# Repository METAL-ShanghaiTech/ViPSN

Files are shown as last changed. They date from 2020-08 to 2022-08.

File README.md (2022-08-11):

# ViPSN 2.0 (debug version)

English | [简体中文](./README.zh-CN.md)

**ViPSN** (acronym of vibration-powered sensing node) is a programmable Internet of Things (IoT) platform for the development of vibration- or motion-powered sensing and transmitting systems. It serves as a reconfigurable developing platform for vibration-powered IoT applications.

<!-- ## System overview -->

<!-- ## Project structure -->

## Setup and usage

Coming soon! This is debug version (2021-03-05) of ViPSN. 
Right now we are working on a way to get hardware to users, please contact the authors for more information (email: lixin1@shanghaitech.edu.cn or liangjr@shanghaitech.edu.cn). 
For now, feel **free** to explore the hardware and software designs, but be sure to **cite** our work.
```
@ARTICLE{9169698,
  author={X. {Li} and L. {Teng} and H. {Tang} and J. {Chen} and H. {Wang} and Y. {Liu} and M. {Fu} and J. {Liang}},
  journal={IEEE Internet of Things Journal}, 
  title={ViPSN: A Vibration-Powered IoT Platform}, 
  year={2021},
  volume={8},
  number={3},
  pages={1728-1739},
  doi={10.1109/JIOT.2020.3016993}}
```
## Prerequisites
### Hardware design
- Altium Designer (version 9.4 or above) is used for the PCB design.
### Software design
- Keil5 is required to compile the software. 

<!-- ### Software Provided 

In **EGU** and **ETU** folders, this project provides the [Audio](./VSU/Audio/Example) file, which is played by resonant speaker. [AudioGenerator](./VSU/Audio/AudioGenerator.m) can be edited to generate a stable audio wave and . Also, the 3D model file is provided. More details are shown in [VSU README.md](./VSU/README.md).

In **EEU** folder, here are four types circuit model, SEH, self-power P-SSHI, self-power SECE, self-power S-SSHI.

In **EMU** folder, here is a PCB file.

In **EUU** folder, this project provides the [Transmitter Part](.\EUU\software\EUU_trans\examples) and [Receive Part](.\EUU\software\Receiver). And [PCB file](.\EUU\pcb) is also included.  -->

## Related publications
- Qiang Liu, Xin Li, Hao Zhang, Jing Ren*, Shuo Yang, Leitao Cao, Junrui Liang*, Shengjie Ling*, "IntelliSense silk fibroin ionotronic batteries for wildfire detection and alarm," Nano Energy, vol. 101, art. no. 107630, Oct. 2022.
- Jianjun Wang*, Yalei Cao, Hongjun Xiang, Zhiwei Zhang, Junrui Liang, Xin Li, Deyun Ding, Teng Li, and Lihua Tang, "A piezoelectric smart backing ring for high-performance power generation subject to train induced steel-spring fulcrum forces," Energy Conversion and Management, vol. 257, art. no. 115442, 2022.
- Jinxi Zhang, Shaobo Gong, Xin Li, Junrui Liang, Zhong Lin Wang*, and Kailiang Ren*, "A wind‐driven poly (tetrafluoroethylene) electret and polylactide polymer‐based hybrid nanogenerator for self‐powered temperature detection system," Advanced Sustainable Systems, art. no. 2000192. 2021.
- Xin Li, Li Teng, Hong Tang, Haoyu Wang, Yu Liu, Minfan Fu, and Junrui Liang*, “ViPSN: a vibration-powered IoT platform,” IEEE Internet of Things Journal, vol. 8, no. 3, pp. 1728-1739, 2021. 
- Xin Li, Hong Tang, Yiyao Zhu and Junrui Liang*, “Power solution of a vibration-powered sensing node,” Proceedings of the 9th International Power Electronics and Motion Control Conference, Nanjing, China, May 31-June 3, 2020. (IPEMC - ECCE Asia 2020). 
- Xin Li, Hong Tang, Bao Zhao, and Junrui Liang*, “System design and implementation of a transient-motion-powered IoT sensor node,” Proceedings of the ASME 2020 Conference on Smart Materials, Adaptive Structures and Intelligent Systems, Irvine, CA, USA, September 14–16, 2020. (SMASIS 2020) (Finalist of Best Student Hardware Competision).
- Xin Li, Hong Tang, Junrui Liang*, and Lihua Tang, "Exploring the magnetic plucking motion towards a transient-motion-powered IoT sensor node", Proceedings of SPIE Conference 11376, Active and Passive Smart Structures and Integrated Systems IX, 113761U, 22 April 2020. (SPIE SS/NDE 2020).
- Kang Zhao, Yuheng Zhao, and Junrui Liang*, “Live Demo of A Vibration-Powered Bluetooth Sensor with Running PFC Power Conditioning”, Proceedings of the 2017 IEEE International Symposium on Circuits and Systems, Baltimore, USA, May 2017. (ISCAS 2017).
- Kang Zhao, Yuheng Zhao, and Junrui Liang*, “A vibration-powered Bluetooth wireless sensor node with running PFC power conditioning”, Proceedings of the 2017 IEEE International Symposium on Circuits and Systems, Baltimore, USA, May 2017. (ISCAS 2017).

## Contributors
- Yuheng Zhao and Kang Zhao contributed early on to the hardware designs in 2017.
- Xin Li proposed and designed the system of ViPSN in 2019. 
- Hong Tang implemented the hardwares of system.
- Prof. Junrui Liang oversaw, funded, and originated the project.

## Funding
This research was supported by the grants from the National Natural Science Foundation of China (Project No. 61401277) and ShanghaiTech University (Project No. F-0203-13-003).

## License
```
Apache License
Copyright 2020 Xin Li and Junrui Liang.

Licensed under the Apache License, Version 2.0 (the "License");
you may not use this file except in compliance with the License.
You may obtain a copy of the License at

    http://www.apache.org/licenses/LICENSE-2.0

Unless required by applicable law or agreed to in writing, software
distributed under the License is distributed on an "AS IS" BASIS,
WITHOUT WARRANTIES OR CONDITIONS OF ANY KIND, either express or implied.
See the License for the specific language governing permissions and
limitations under the License.
```
## Contact
If you have technical problems, please contact: lixin1@shanghaitech.edu.cn or china.lixin1@gmail.com.

For business cooperation, please contact: liangjr@shanghaitech.edu.cn.

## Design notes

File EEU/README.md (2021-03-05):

# Energy Enhancement Unit (EEU)

The **EEU** offers the following options:

- standard interface circuit ([SEH]);
- self-power parallel synchronized switch harvesting on inductor  ([SP-P-SSHI]);
- self-power series synchronized switch harvesting on inductor  ([SP-S-SSHI]).

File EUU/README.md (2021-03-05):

# Energy User Unit (EUU)

A programmable BLE SoC (system on chip) nRF52832 by Nordic Inc. serves as the EUU. The EUU has three parts: transceiver, sensor, and CPU. The sensor part uses the on-chip temperature sensor in nRF52832. 
Two remote edge devices are designed for receiving the signals sent out by ViPSN. 
One is a cell phone, which runs a customized mobile app as the EDU module. 
Another is a host PC, which installs a USB BLE receiver module and data processing
program. 
More detailed explanation can be referred to paper ([ViPSN: A Vibration-Powered IoT Platform](../README.md/#divtop)).

## Software

The EUU software includes the two version:

- ESB

    - [Example 1](./software/ESB_version/Transmitter_for_EUU/examples/ESB_template/case_of_intermittent_vibrations/pca10040/blank/arm5_no_packs/)
    - [Example 2](./software/ESB_version/Transmitter_for_EUU/examples/ESB_template/case_of_transient_excitation/pca10040/blank/arm5_no_packs/)
    - [Receiver](./software/ESB_version/Receiver_for_EUU/project/)

    The main differences between above two examples are as follows:

    ```c
    //it has two types of timer, one is being ticked repeating with the interval set before     
    err_code = app_timer_create(&m_led_toggle_timer_id,
                                    APP_TIMER_MODE_REPEATED,
                                    led_toggle_timeout_handler);
    ```

    ```c
    //the other is being ticked singlely	
    err_code = app_timer_create(&m_led_toggle_timer_id,
                                APP_TIMER_MODE_SINGLE_SHOT,
                                led_toggle_timeout_handler);
    ```

- BLE beacon
    - [Example 3](./software/beacon_version/examples/ble_peripheral/ble_app_beacon/pca10040/s132/arm5_no_packs/)

<!-- ## How to install keil5

 Go to [here](http://www2.keil.com/mdk5 ) to download keil5.

It is necessary to activate keil5 before compiling code.

Device is nordic nRF52832-QFAA.

The following pack are required after installing keil5:

1. NordicSemiconductor.nRF_DeviceFamilyPack.8.17.0.pack
2. NordicSemiconductor::Device:Startup:8.9.0
3. ARM.CMSIS.4.5.0

When open [project](.\EUU\software\EUU_trans\examples\case of bridge vibration\pca10040\blank\arm5_no_packs), the dialog box will pop and remind installing above packs. 

After automatically installing, keil5 can complier the project. 

JLINK is recommended to download hex file. If JLINK is not available for developers, STLINK is also available.  -->

<!-- ### Code & Project

In EUU, there are two example projects. 

Developers should build and download it. If something go wrong, please read **Problems may encountered**.

The brief explanation for the project is following:

#### Bridge 

Code can be opened [here](.\EUU\software\EUU_trans\examples\case of bridge vibration\pca10040\blank\arm5_no_packs).

**BUTTON_TOUCH** is the IO port set. 

When **BUTTON_TOUCH** is rising edge, IO interrupt starts. 

When it is falling edge, IO interrupt stops. 

When IO interrupt starts, a timer starts at the same time. 

The timer is set by **LED_TOGGLE_INTERVAL**. 

After timer overflows, **led_toggle_timeout_handler** function is called. 

In this case, it only has a function named **s_tx()**. Developers can change this function to its custom function. 

This function starts high frequency clk at the beginning, then collecting temperature sensor data, sending by ESB, delaying 200ms, and then changing clk from high frequency to low frequency.

In this Bridge case, the timer will repeat according to **LED_TOGGLE_INTERVAL**. And it repeats until IO port is falling edge.

#### Transient 

Code can be opened [here](.\EUU\software\EUU_trans\examples\case of transient excitation\pca10040\blank\arm5_no_packs).

**BUTTON_TOUCH** is the IO port set. 

When **BUTTON_TOUCH** is rising edge, IO interrupt starts. 

When it is falling edge, IO interrupt stops. 

When IO interrupt starts, a timer starts at the same time. 

The timer is set by **LED_TOGGLE_INTERVAL**. 

After timer overflows, **led_toggle_timeout_handler** function is called. Then the timer closes before IO detects it is falling edge. 

In this case, it only has a function named **s_tx()**. Developers can change this function to its custom function. 

This function starts high frequency clk at the beginning, then collecting temperature sensor data, sending by ESB, delaying 200ms, and then changing clk from high frequency to low frequency.

In this Transient case, the timer will only be singly ticked. And it repeats until IO port is falling edge. -->

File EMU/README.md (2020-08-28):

# Energy Management Unit (EMU)

<!-- **EMU** plays an essential role to guarantee the robust and reliable operation under complicated vibration conditions.
It is responsible not only for providing temporary capacitive energy storage for the extra harvested energy from **ETU**, but also for supplying power at a constant voltage to **EUU**.
On the other hand, many vibration sources are intermittent, variable, and unpredictable, so vibration-powered devices should operate in various vibration environments, such as intermittent mode or transient mode.
**EMU** has to maximize the harvested energy income from the supply side, minimize the energy dissipation in energy conversion, and properly deliver power on the user’s demand.
The software program should be carried out with an awareness of the stored energy
level.
However, most off-the-shelf commercial regulators IC only emphasized stable logic voltage output.
Necessary interactions between energy storage and EUU were not sufficiently supported.
For example, LTC3588 (Linear Technology Co.) integrates a low-loss full-wave bridge rectifier and a high-efficiency buck converter for PEH power conditioning.
Its power good output pin (PGOOD) is actually used for indicating the availability of stable output voltage, rather than the stored energy level. -->

In this project, an enhanced EMU is developed by making complementary design to the off-the-shelf commercial regulator. 
It produces necessary energy-level indicating signals to the energy user for better operation under fluctuating or intermittent vibrations.
EMU has three parts: 
1. LTC3588 is used for regulation purpose. Its dc-dc power conversion efficiency is around 80% to 90% under different input voltage, output voltage, and loading current. 
2. MIC841, a micro-power, precision-voltage comparator with adjustable hysteresis is used to provide energy indicating signals.
Via adjusting the resistor network, we can change the threshold of stored energy level so that to carry out different functions.
3. A capacitor is used to store harvested energy.

During the operation, the EMU provides two internal energy-level indicating signals to itself and three external signals to the EUU, such that **ViPSN** can properly handle different tasks. 
P<sub>start</sub> sets when V<sub>store</sub> > 5 V and P<sub>close</sub> sets when V<sub>store</sub> < 3.4 V. 
P<sub>start</sub> starts the dc-dc power conversion of LTC3588. 
P<sub>close</sub> turns off the converter. 
There might be several rounds of lockouts and restarts before the output voltage reaches a stable level, because of the depletion and refill of the storage capacitor. 
Besides the fixed UVLO thresholds, the PGOOD pin of LTC3588 offers further information on the output voltage stability.
The PGOOD pin is logic high when the output voltage of LTC3588 is above 92% of the desired regulation voltage. 
If Vcc falls below this threshold, it turns to logic low. 
It should be noted that PGOOD is not a storage-level indicating signal. 
P<sub>good</sub> added in this study provides a real storage-level indicating signal.
It comes with the rising edge of the comparator’s output. 
It denotes that the storage capacitor of EMU has gained sufficient energy to ensure the execution of the most power-consuming atomic operation. 
P<sub>sleep</sub> comes with the falling edge of the comparator’s output. 
It warns that the energy storage of EMU is in shortage; therefore, the EUU must take an emergent process to save the critical data and then go to the ultralowpower deep-sleep mode. 
In addition, via adjusting the resistor network of the comparator, we can change the voltage thresholds for generating P<sub>good</sub> and P<sub>sleep</sub> so as to ensure proper operations under different excitation conditions.

More information about the working principle of EMU can be referred to paper ([ViPSN: A Vibration-Powered IoT Platform](../README.md/#divtop) and [Power solution of a vibration-powered sensing node](../README.md/#divtop2)).

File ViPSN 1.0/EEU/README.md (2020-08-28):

# Energy Enhancement Unit (EEU)

The **EEU** offers the following options:

- standard interface circuit ([SEH](./circuit/SEH));
- self-power parallel synchronized switch harvesting on inductor  ([SP-P-SSHI](./circuit/SP-P-SSHI));
- self-power series synchronized switch harvesting on inductor  ([SP-S-SSHI](./circuit/SP-S-SSHI)).

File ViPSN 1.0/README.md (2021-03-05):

# ViPSN 1.0
ViPSN

**ViPSN** (acronym of vibration-powered sensing node) is a programmable Internet of Things (IoT) platform for the development of vibration- or motion-powered sensing and transmitting systems. It serves as a reconfigurable developing platform for vibration-powered IoT applications. The whole set of **ViPSN** assembles six basic modules: a vibration emulator as the energy generation unit (**EGU**); a piezoelectric transducer as the energy transduction unit (**ETU**); a power-boosting interface circuit as the energy enhancement unit (**EEU**); a dc-dc regulator with energy-level indicating signals as the energy management unit (**EMU**); a Bluetooth low energy (BLE) module as the energy user unit (**EUU**); and a mobile app as the edge demonstration unit (**EDU**). All units or modules are connected with easy mechanical joggle joints and electrical plunger pin contacts.

## Prerequisites
### Hardware design
- Altium Designer (version 9.4 or above) is used for the PCB design.
- Solidworks (version 2018 or above) is used for 3D-printer case.
### Software design
- Keil5 is required to compile the software. 

### Specification
<table style="border-collapse: collapse; border: none; border-spacing: 0px;">
	<tr>
		<td style="border-width: 1px; border-style: solid; border-color: rgb(0, 0, 0); text-align: center; padding-right: 3pt; padding-left: 3pt;">
			<b>Unit</b>
		</td>
		<td colspan="3" style="border-width: 1px; border-style: solid; border-color: rgb(0, 0, 0); text-align: center; padding-right: 3pt; padding-left: 3pt;">
			<b>Specification</b>
		</td>
	</tr>
	<tr>
		<td style="border-width: 1px; border-style: solid; border-color: rgb(0, 0, 0); text-align: center; padding-right: 3pt; padding-left: 3pt;">
			EGU
		</td>
		<td style="border-width: 1px; border-style: solid; border-color: rgb(0, 0, 0); text-align: center; padding-right: 3pt; padding-left: 3pt;">
			Resonant speaker
		</td>
		<td style="border-width: 1px; border-style: solid; border-color: rgb(0, 0, 0); text-align: center; padding-right: 3pt; padding-left: 3pt;">
			Type
		</td>
		<td style="border-width: 1px; border-style: solid; border-color: rgb(0, 0, 0); text-align: center; padding-right: 3pt; padding-left: 3pt;">
			ADIN-B1BT
		</td>
	</tr>
	<tr>
		<td rowspan="4" style="border-width: 1px; border-style: solid; border-color: rgb(0, 0, 0); text-align: center; padding-right: 3pt; padding-left: 3pt;">
			ETU
		</td>
		<td rowspan="2" style="border-width: 1px; border-style: solid; border-color: rgb(0, 0, 0); text-align: center; padding-right: 3pt; padding-left: 3pt;">
			Piezoelectric
			<br>
			 transducer
		</td>
		<td style="border-width: 1px; border-style: solid; border-color: rgb(0, 0, 0); text-align: center; padding-right: 3pt; padding-left: 3pt;">
			Diameter
		</td>
		<td style="border-width: 1px; border-style: solid; border-color: rgb(0, 0, 0); text-align: center; padding-right: 3pt; padding-left: 3pt;">
			30 mm
		</td>
	</tr>
	<tr>
		<td style="border-width: 1px; border-style: solid; border-color: rgb(0, 0, 0); text-align: center; padding-right: 3pt; padding-left: 3pt;">
			Material
		</td>
		<td style="border-width: 1px; border-style: solid; border-color: rgb(0, 0, 0); text-align: center; padding-right: 3pt; padding-left: 3pt;">
			PZT sheet on steel
		</td>
	</tr>
	<tr>
		<td rowspan="2" style="border-width: 1px; border-style: solid; border-color: rgb(0, 0, 0); text-align: center; padding-right: 3pt; padding-left: 3pt;">
			Mass
		</td>
		<td style="border-width: 1px; border-style: solid; border-color: rgb(0, 0, 0); text-align: center; padding-right: 3pt; padding-left: 3pt;">
			Weight
		</td>
		<td style="border-width: 1px; border-style: solid; border-color: rgb(0, 0, 0); text-align: center; padding-right: 3pt; padding-left: 3pt;">
			13 g
		</td>
	</tr>
	<tr>
		<td style="border-width: 1px; border-style: solid; border-color: rgb(0, 0, 0); text-align: center; padding-right: 3pt; padding-left: 3pt;">
			Material
		</td>
		<td style="border-width: 1px; border-style: solid; border-color: rgb(0, 0, 0); text-align: center; padding-right: 3pt; padding-left: 3pt;">
			Steel
		</td>
	</tr>
	<tr>
		<td rowspan="2" style="border-width: 1px; border-style: solid; border-color: rgb(0, 0, 0); text-align: center; padding-right: 3pt; padding-left: 3pt;">
			EEU
		</td>
		<td style="border-width: 1px; border-style: solid; border-color: rgb(0, 0, 0); text-align: center; padding-right: 3pt; padding-left: 3pt;">
			SEH
		</td>
		<td colspan="2" style="border-width: 1px; border-style: solid; border-color: rgb(0, 0, 0); text-align: center; padding-right: 3pt; padding-left: 3pt;">
			Full-wave bridge rectifier
		</td>
	</tr>
	<tr>
		<td style="border-width: 1px; border-style: solid; border-color: rgb(0, 0, 0); text-align: center; padding-right: 3pt; padding-left: 3pt;">
			SP-SSHI
		</td>
		<td colspan="2" style="border-width: 1px; border-style: solid; border-color: rgb(0, 0, 0); text-align: center; padding-right: 3pt; padding-left: 3pt;">
			Parallel SP-SSHI
		</td>
	</tr>
	<tr>
		<td rowspan="3" style="border-width: 1px; border-style: solid; border-color: rgb(0, 0, 0); text-align: center; padding-right: 3pt; padding-left: 3pt;">
			EMU
		</td>
		<td style="border-width: 1px; border-style: solid; border-color: rgb(0, 0, 0); text-align: center; padding-right: 3pt; padding-left: 3pt;">
			DC-DC Converter
		</td>
		<td colspan="2" style="border-width: 1px; border-style: solid; border-color: rgb(0, 0, 0); text-align: center; padding-right: 3pt; padding-left: 3pt;">
			LTC3588-1
		</td>
	</tr>
	<tr>
		<td style="border-width: 1px; border-style: solid; border-color: rgb(0, 0, 0); text-align: center; padding-right: 3pt; padding-left: 3pt;">
			Comparator
		</td>
		<td colspan="2" style="border-width: 1px; border-style: solid; border-color: rgb(0, 0, 0); text-align: center; padding-right: 3pt; padding-left: 3pt;">
			MIC841
		</td>
	</tr>
	<tr>
		<td style="border-width: 1px; border-style: solid; border-color: rgb(0, 0, 0); text-align: center; padding-right: 3pt; padding-left: 3pt;">
			Storage
		</td>
		<td colspan="2" style="border-width: 1px; border-style: solid; border-color: rgb(0, 0, 0); text-align: center; padding-right: 3pt; padding-left: 3pt;">
			Electrolytic capacitor
		</td>
	</tr>
	<tr>
		<td rowspan="2" style="border-width: 1px; border-style: solid; border-color: rgb(0, 0, 0); text-align: center; padding-right: 3pt; padding-left: 3pt;">
			EUU
		</td>
		<td style="border-width: 1px; border-style: solid; border-color: rgb(0, 0, 0); text-align: center; padding-right: 3pt; padding-left: 3pt;">
			SoC
		</td>
		<td colspan="2" style="border-width: 1px; border-style: solid; border-color: rgb(0, 0, 0); text-align: center; padding-right: 3pt; padding-left: 3pt;">
			nRF52832
		</td>
	</tr>
	<tr>
		<td style="border-width: 1px; border-style: solid; border-color: rgb(0, 0, 0); text-align: center; padding-right: 3pt; padding-left: 3pt;">
			Software
		</td>
		<td colspan="2" style="border-width: 1px; border-style: solid; border-color: rgb(0, 0, 0); text-align: center; padding-right: 3pt; padding-left: 3pt;">
			nRF5 SDK V15.2
		</td>
	</tr>
</table>

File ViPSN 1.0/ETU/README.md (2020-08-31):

## Energy Transduction Unit (ETU)
For ETU, the piezoelectric transducer is made of a circular low-cost piezoelectric buzzer, whose rim is fixed at the moving part of the resonance speaker. 
The low-cost generator is good for popularization. 
If this cheap and under-performing structure works well, there is no doubt for other more sophisticated designs. 
A mass is bonded at the center of the round-shape transducer.
When the base (moving part of the vibrator) undergoes vibration, the piezoelectric structure deflects.

### Specification

<table style="border-collapse: collapse; border: none; border-spacing: 0px;">
	<tr>
		<td style="border-width: 1px; border-style: solid; border-color: rgb(0, 0, 0); text-align: center; padding-right: 3pt; padding-left: 3pt;">
			<b>Unit</b>
		</td>
		<td colspan="3" style="border-width: 1px; border-style: solid; border-color: rgb(0, 0, 0); text-align: center; padding-right: 3pt; padding-left: 3pt;">
			<b>Specification</b>
		</td>
	</tr>
	<tr>
		<td rowspan="4" style="border-width: 1px; border-style: solid; border-color: rgb(0, 0, 0); text-align: center; padding-right: 3pt; padding-left: 3pt;">
			ETU
		</td>
		<td rowspan="2" style="border-width: 1px; border-style: solid; border-color: rgb(0, 0, 0); text-align: center; padding-right: 3pt; padding-left: 3pt;">
			Piezoelectric
			<br>
			 transducer
		</td>
		<td style="border-width: 1px; border-style: solid; border-color: rgb(0, 0, 0); text-align: center; padding-right: 3pt; padding-left: 3pt;">
			Diameter
		</td>
		<td style="border-width: 1px; border-style: solid; border-color: rgb(0, 0, 0); text-align: center; padding-right: 3pt; padding-left: 3pt;">
			30 mm
		</td>
	</tr>
	<tr>
		<td style="border-width: 1px; border-style: solid; border-color: rgb(0, 0, 0); text-align: center; padding-right: 3pt; padding-left: 3pt;">
			Material
		</td>
		<td style="border-width: 1px; border-style: solid; border-color: rgb(0, 0, 0); text-align: center; padding-right: 3pt; padding-left: 3pt;">
			PZT sheet on steel
		</td>
	</tr>
	<tr>
		<td rowspan="2" style="border-width: 1px; border-style: solid; border-color: rgb(0, 0, 0); text-align: center; padding-right: 3pt; padding-left: 3pt;">
			Mass
		</td>
		<td style="border-width: 1px; border-style: solid; border-color: rgb(0, 0, 0); text-align: center; padding-right: 3pt; padding-left: 3pt;">
			Weight
		</td>
		<td style="border-width: 1px; border-style: solid; border-color: rgb(0, 0, 0); text-align: center; padding-right: 3pt; padding-left: 3pt;">
			13 g
		</td>
	</tr>
	<tr>
		<td style="border-width: 1px; border-style: solid; border-color: rgb(0, 0, 0); text-align: center; padding-right: 3pt; padding-left: 3pt;">
			Material
		</td>
		<td style="border-width: 1px; border-style: solid; border-color: rgb(0, 0, 0); text-align: center; padding-right: 3pt; padding-left: 3pt;">
			Steel
		</td>
	</tr>
</table>

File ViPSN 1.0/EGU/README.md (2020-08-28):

## Energy Generation Unit (EGU)
For EGU, a commercial portable resonance speaker serves as the vibrator.
It generates vibrations according to the records from real-world environments. 
It is self-contained with a battery pack inside and standard auxiliary port (AUX) for audio input. 
Different from a normal loudspeaker, it does not have a diaphragm. 
It produces sounds by vibrating the contacting hard medium. 
In other words, a resonance speaker can convert the audio signal into structural vibration.
Compared with the expensive and heavy professional vibrator, this portable solution is a better option for the developer working on vibration-powered IoT applications.

### Specification
In this project, we provided a script (acc2wav.m) to convert vibration acceleration data into audio signals.

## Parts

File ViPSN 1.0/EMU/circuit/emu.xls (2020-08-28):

Comment | Description | Designator | Footprint | LibRef | Quantity
CAP | Capacitor | C3, C4 | 6-0805_N | CAP | 2
6.3V | Polarized Capacitor (Radial) | Cr | 3216[1206] | Cap Pol1 | 1
Cap Pol1 | Polarized Capacitor (Radial) | Cstore | HDR1X2 | Cap Pol1 | 1
Socket | Socket | J1, J2, J3, J4, J7, J11 | PIN1 | Socket | 6
10uH |  | L2 | SMD SS16 | INDUCTOR | 1
Res1 | Resistor | Rc1, Rc2, Rc3 | 6-0805_N | Res1 | 3
LTC3588-1 | Nanopower energy harvesting power supply | U1 | LTC 3588-1 | LTC3588-1 | 1
MIC841 |  | U2 | SOT65P210X90-5L20N | Component_1 | 1

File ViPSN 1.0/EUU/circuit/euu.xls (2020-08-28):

Comment | Description | Designator | Footprint | LibRef | Quantity
4.7uF | Capacitor, NP0, ±2% | C1 | 0603C |  | 1
1uF | Capacitor, NP0, ±2% | C2 | 0603C |  | 1
12pF | Capacitor, NP0, ±2% | C3, C5, C10, C18 | 0603C | C0402-12p | 4
100nF | Capacitor, NP0, ±2% | C4, C6, C14 | 0603C |  | 3
100pF | Capacitor, NP0, ±2% | C8 | 0603C |  | 1
NC | Capacitor, NP0, ±2% | C9 | 0603C |  | 1
0.8pF | Capacitor, NP0, ±2% | C13 | 0603C |  | 1
 |  | DEBUG1 | SIP4 - 2.0 | Header 4 | 1
Socket | Socket | J1, J2, J3, J4, J7, J11 | PIN1 | Socket | 6
10uH | High frequency chip inductor ±5% | L1 | 0603 |  | 1
15nH | High frequency chip inductor ±5% | L2, L3 | 0603 |  | 2
nRF52832-QFAA | Multi-protocol Bluetooth Low Energy and 2.4GHz proprietary system-on-chip | U1 | QFN48 |  | 1
32MHz | XTAL SMD 2016, 32MHz, Cl=8pF, Tol: ±10ppm, Stab: ±10ppm | X1 | BT-XTAL_2016 | XTAL_SMD2016_32MHz_8pF_Epson | 1
32.768kHz | EPSON TOYOCOM - FC-135 32.768KHZ ±20PPM,9.0PF - CRYSTAL, SM, WATCH | X2 | XTAL_3215 | XTAL_FC-135 32.768k | 1

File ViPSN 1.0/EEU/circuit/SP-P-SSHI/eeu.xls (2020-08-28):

Comment | Description | Designator | Footprint | LibRef | Quantity
680pF/50V | 贴片电容 | C11, C12 | 0603C | CAP | 2
SS14 | 1 Amp General Purpose Rectifier | D1, D2, D3, D4, D5 | SOD323 | Diode 1N4004 | 5
SS16 | 1 Amp General Purpose Rectifier | D6 | SOD323 | Diode 1N4004 | 1
Socket | Socket | J1, J2, J3, J4, J7, J11 | PIN1 | Socket | 6
1mH |  | L4 | 1812 | INDUCTOR | 1
510K | 贴片电阻 | R1, R2 | 0603 | Res1 | 2
XN4601 | Composite Transistors, XN4601 | T1, T2 | XN4601 | XN4601 | 2

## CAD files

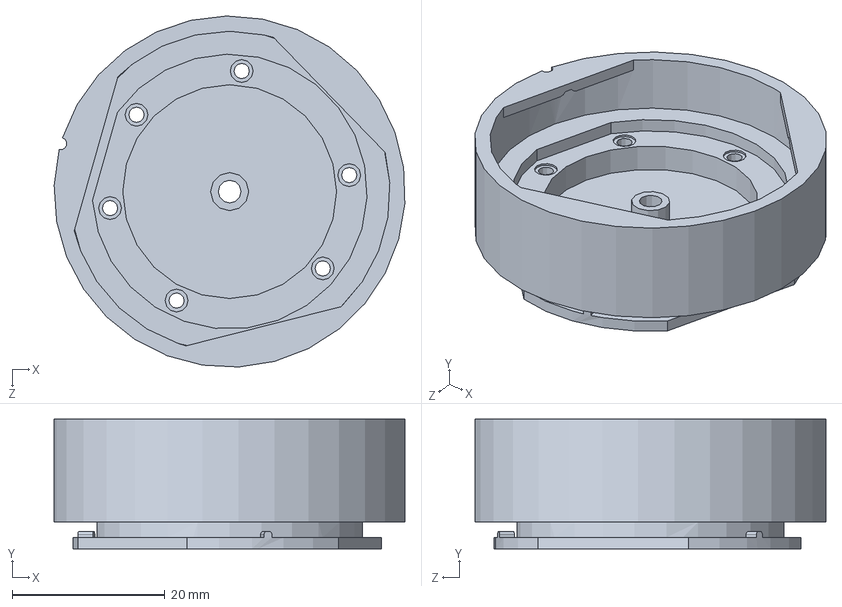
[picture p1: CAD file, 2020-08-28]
ViPSN 1.0/EEU/3d_printer/eeu.SLDPRT
45.9 x 17.0 x 46.0 mm

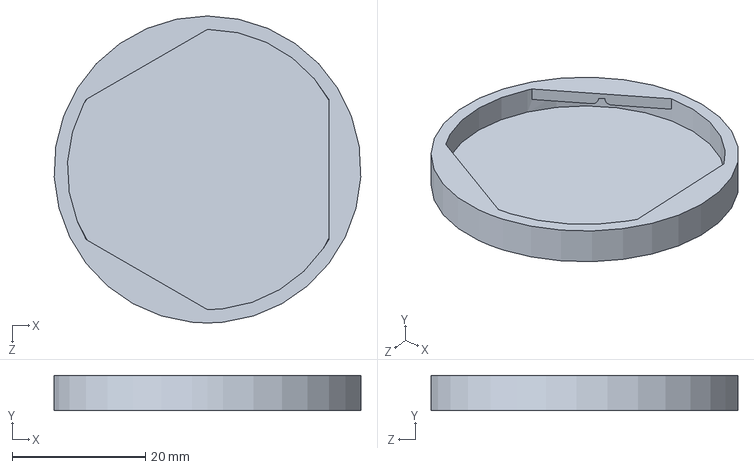
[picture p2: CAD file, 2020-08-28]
ViPSN 1.0/EGU/3d_printer/egu.SLDPRT
45.9 x 5.30 x 46.0 mm

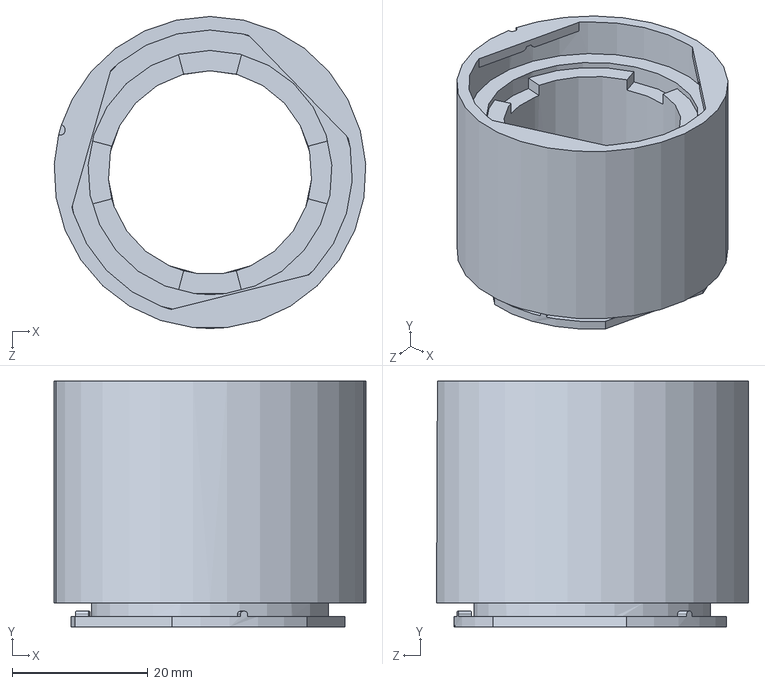
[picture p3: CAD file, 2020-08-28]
ViPSN 1.0/ETU/3d_printer/etu-1.SLDPRT
45.9 x 36.2 x 46.0 mm

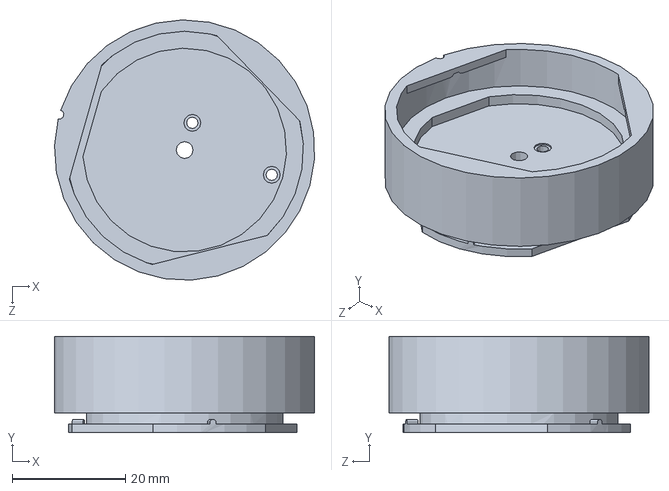
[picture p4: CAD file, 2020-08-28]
ViPSN 1.0/ETU/3d_printer/etu-2.SLDPRT
45.9 x 17.0 x 46.0 mm

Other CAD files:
ViPSN 1.0/EMU/3d_printer/emu.SLDPRT
ViPSN 1.0/EUU/3d_printer/euu.SLDPRT

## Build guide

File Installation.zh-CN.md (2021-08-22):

# EUU环境搭建与测试

## 一、准备工作(以Windows 10平台为例)

* `Keil 5 for Arm`(测试版本MDK527)
* `ARM CMSIS`(测试版本4.5.0)
* `NordicSemiconductor.nRF_DeviceFamilyPack`（测试版本8.17.0）
* `Nordic nRF52832`芯片

### 1、安装并激活Keil

**注意：未激活的Keil有编译代码大小的限制，可能无法完成编译工作。**

### 2、安装`ARM CMSIS`和`NordicSemiconductor.nRF_DeviceFamilyPack`

直接双击安装文件，按照提示即可完成安装。

## 二、EUU结构描述

EUU文件夹下的`software`目录中共有两个版本的工程项目，分别对应`Beacon`协议和Nordic自研的`ESB`通信协议。

以`Beacon`版本为例，在`beacon_version`目录下的文件组织形式与Nordic官方提供的`SDK`例程的组织形式类似。由于本项目使用的芯片是`52832`，所以其对应的`Keil`的启动文件在路径`ViPSN\EUU\software\beacon_version\examples\ble_peripheral\ble_app_beacon\pca10040\s132\arm5_no_packs`下面。

## 三、Keil工程编译

双击打开该`Keil`工程，此时可能会遇到`CMSIS`、`DeviceFamilyPack`缺失的信息，由于前面在安装`Keil`的时候已经安装了相应的文件，所以这里我们选择`否`取消安装。这时，在`Keil`的左侧项目视图中，最下面的`CMSIS`以及`Device`显示是红色，编译工程也会出现错误。

error_1

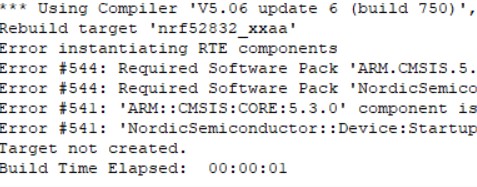
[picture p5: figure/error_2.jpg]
error_2


这时，选择`Keil`上方工具栏中的`Select Software Packs for Target XX`选项卡，在弹出的界面中展开`CMSIS`和`Device Family Pack`选项，取消标红的版本，相应选择刚刚我们自己安装的版本。

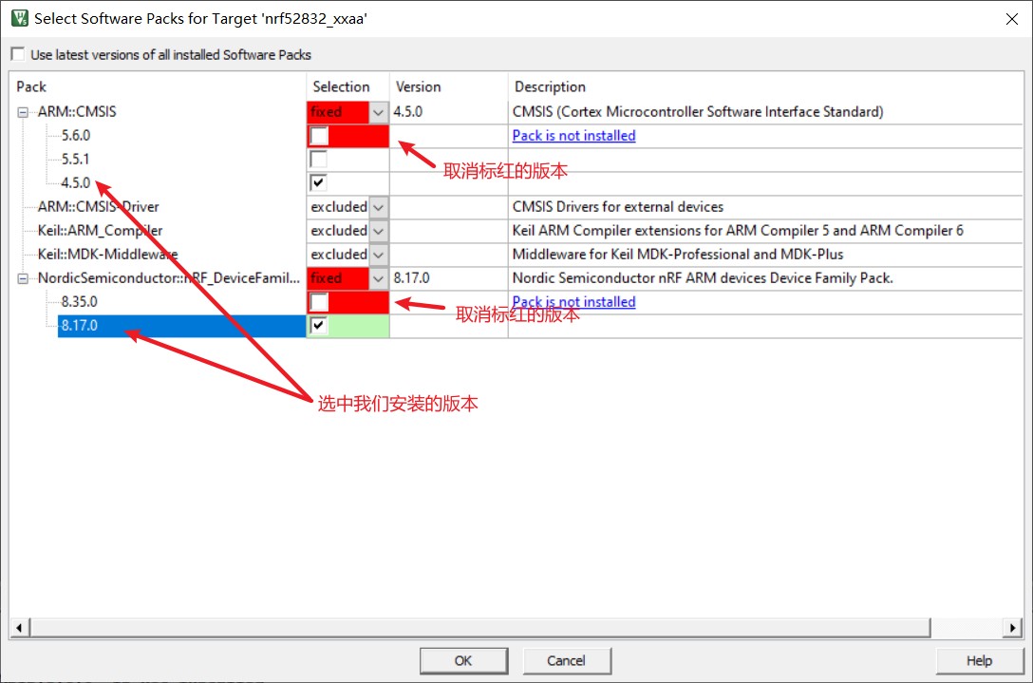
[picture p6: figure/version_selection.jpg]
selection


确定后在弹出的新对话框中，同样展开`CMSIS`以及`Device`选项卡，将标红的版本对应的勾取消。

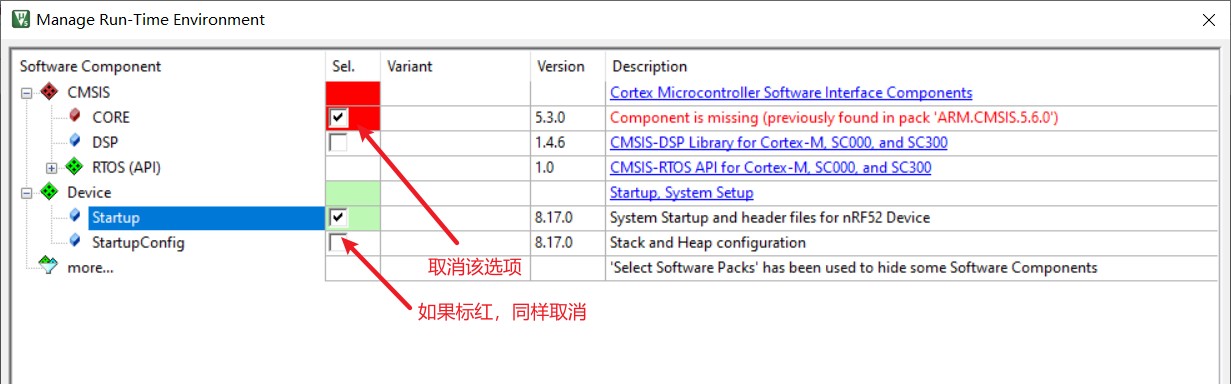
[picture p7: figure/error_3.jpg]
error_3


取消后点击确定关闭该对话框。此时在主界面中，取消的内容会变成灰色。这时进入选项卡`Manage Run-Time Environment`，对应的版本就会更新，按照下图在相应位置前选择即可。

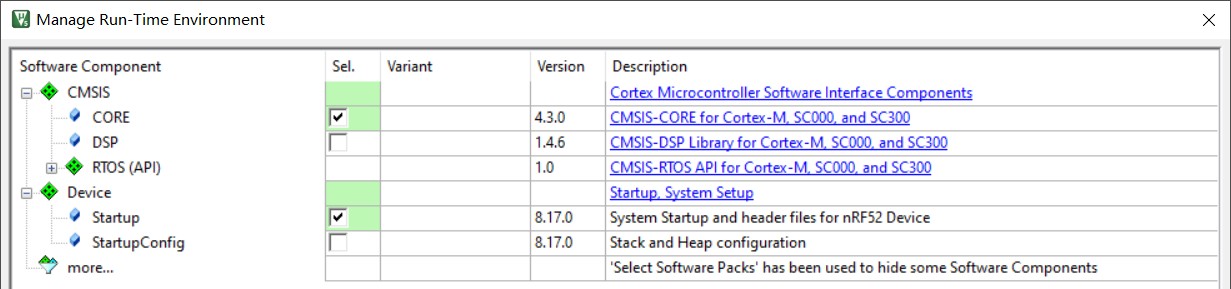
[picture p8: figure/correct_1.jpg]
correct


这时，所有编译前的准备工作完成，选择`Build`选项，即可完成编译。

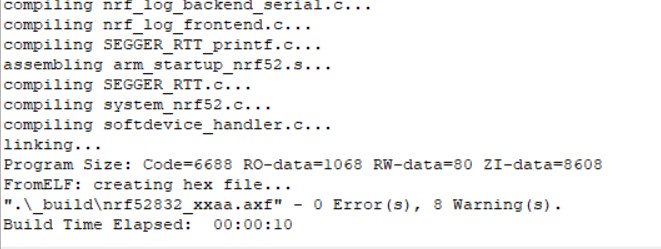
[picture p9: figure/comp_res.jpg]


另外，注意每个项目都会有两个Target，分别对应应用程序和协议栈，其中，应用程序无需再进行额外的操作，可以正常选择`Build`以及`Download`选项。

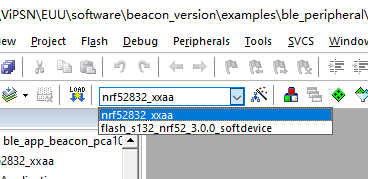
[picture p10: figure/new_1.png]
new_1


但是协议栈Target想要进行`Build`以及`Download`选项则需要注意以下几点：
如果协议栈Target无法成功`Build`，可参考以下方法

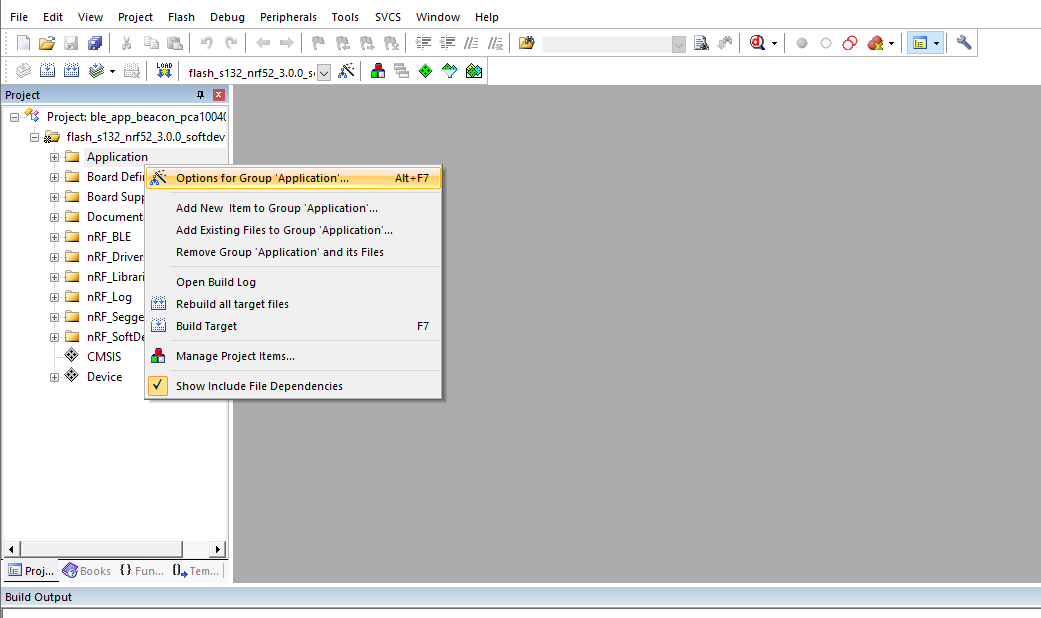
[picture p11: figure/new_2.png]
new_2


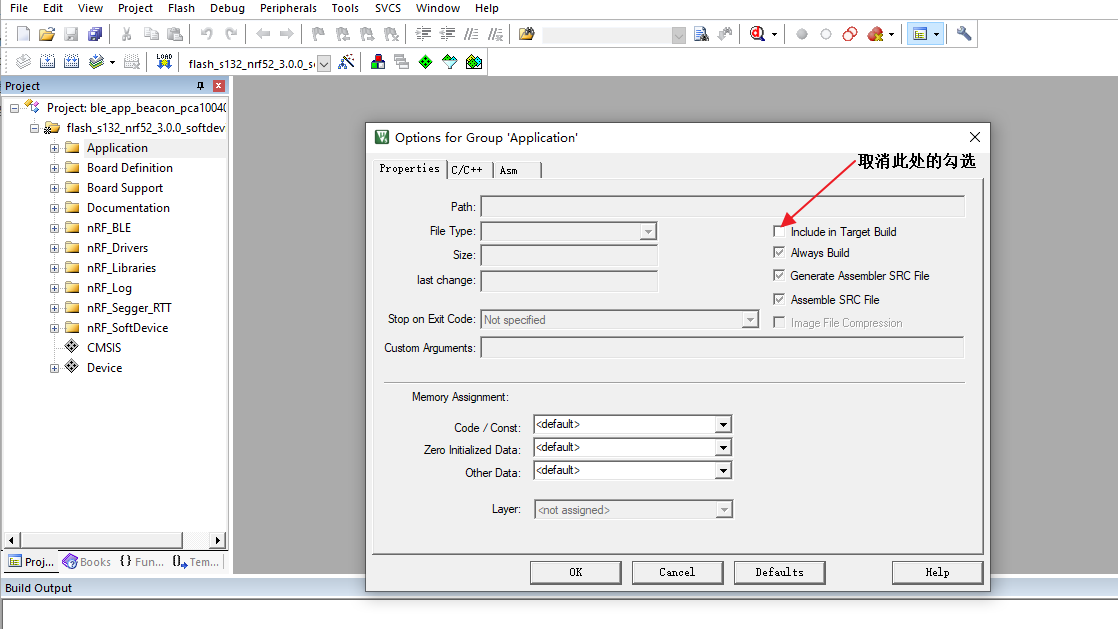
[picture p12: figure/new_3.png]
new_3


对协议栈下所有文件都进行此操作

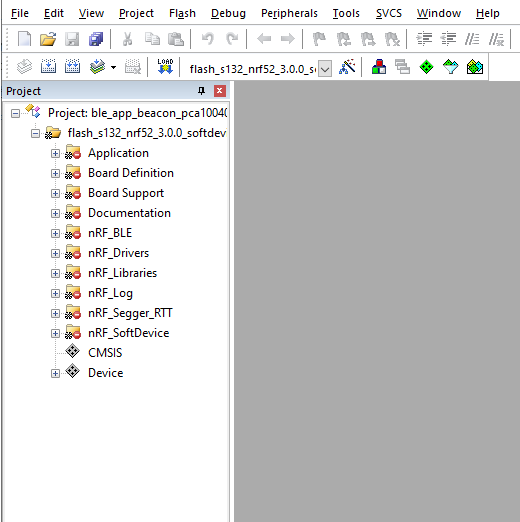
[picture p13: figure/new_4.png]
new_4


如果协议栈Target无法成功`Download`，并出现如下报错

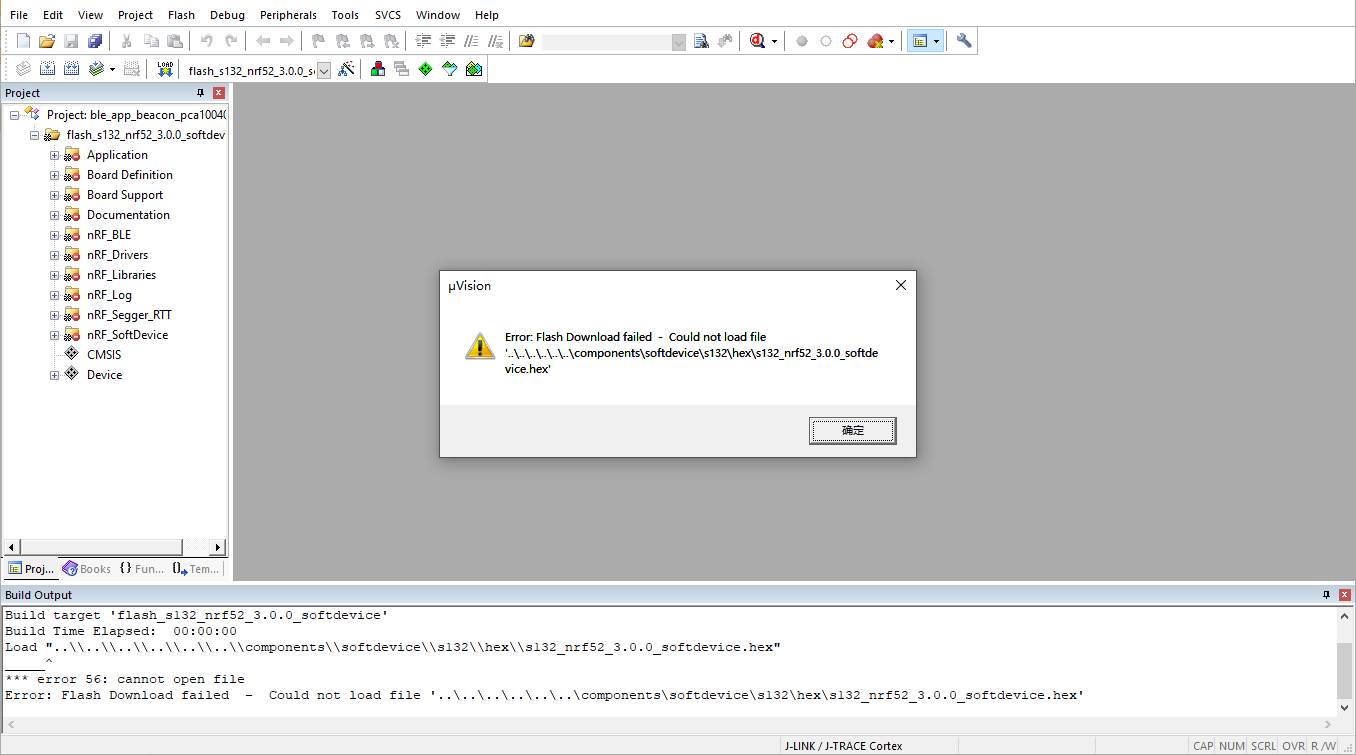
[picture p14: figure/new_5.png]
new_5


这是由于在未按上述步骤操作，直接进行`Build`选项后，协议栈内的.hex文件会被删除，从而无法成功进行`Download`。可选择通过手动添加该协议栈的.hex文件解决报错。

最后是关于对于同一个项目，在`Keil`中进行`Erase`后无法再成功`Download`的情况，报错如下

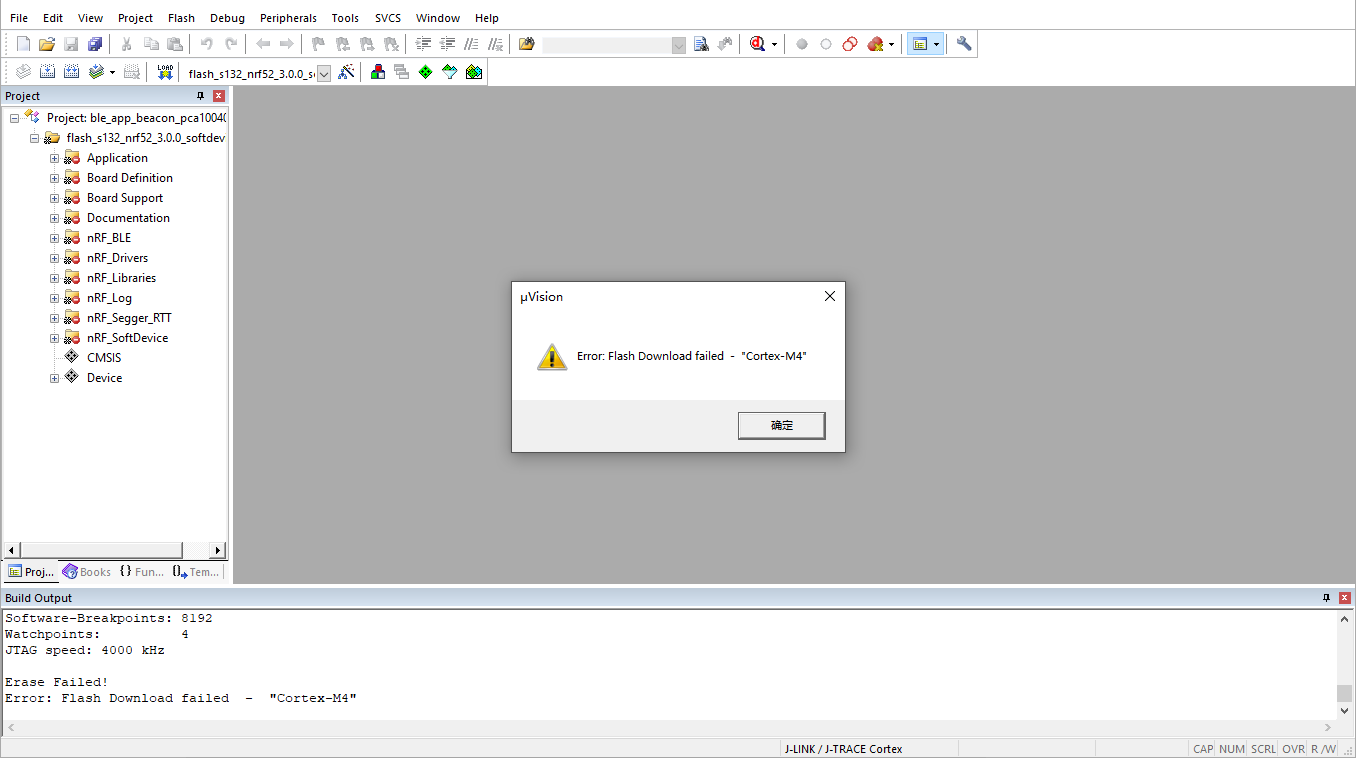
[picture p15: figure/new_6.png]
new_6


这是由于在同一个协议栈Target下，`Erase`操作无法进行完全，可以通过用`Keil`打开另一个不同版本的`Nordic SDK`项目，在另一个不同名的协议栈下进行`Erase`操作，便可完全擦除。再次`Download`之前的协议栈便不会有此报错。

## 注意

本项目默认使用`J-Link`下载代码到芯片，`Keil`同样支持使用`ST-Link`完成下载，但是请在下载前将`Debug`配置从`J-Link`换成`ST-Link`。

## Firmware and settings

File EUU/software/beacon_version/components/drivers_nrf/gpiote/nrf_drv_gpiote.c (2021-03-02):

/* Copyright (c) 2015 Nordic Semiconductor. All Rights Reserved.
 *
 * The information contained herein is property of Nordic Semiconductor ASA.
 * Terms and conditions of usage are described in detail in NORDIC
 * SEMICONDUCTOR STANDARD SOFTWARE LICENSE AGREEMENT.
 *
 * Licensees are granted free, non-transferable use of the information. NO
 * WARRANTY of ANY KIND is provided. This heading must NOT be removed from
 * the file.
 *
 */

#include "sdk_common.h"
#if NRF_MODULE_ENABLED(GPIOTE)
#include "nrf_drv_gpiote.h"
#include "nrf_drv_common.h"
#include "app_util_platform.h"
#include "nrf_assert.h"
#include "nrf_bitmask.h"
#include <string.h>

#define NRF_LOG_MODULE_NAME "GPIOTE"

#if GPIOTE_CONFIG_LOG_ENABLED
#define NRF_LOG_LEVEL       GPIOTE_CONFIG_LOG_LEVEL
#define NRF_LOG_INFO_COLOR  GPIOTE_CONFIG_INFO_COLOR
#define NRF_LOG_DEBUG_COLOR GPIOTE_CONFIG_DEBUG_COLOR
#else // GPIOTE_CONFIG_LOG_ENABLED
#define NRF_LOG_LEVEL       0
#endif  // GPIOTE_CONFIG_LOG_ENABLED
#include "nrf_log.h"
#include "nrf_log_ctrl.h"

/* Validate configuration */
INTERRUPT_PRIORITY_VALIDATION(GPIOTE_CONFIG_IRQ_PRIORITY);

#define FORBIDDEN_HANDLER_ADDRESS ((nrf_drv_gpiote_evt_handler_t)UINT32_MAX)
#define PIN_NOT_USED              (-1)
#define PIN_USED                  (-2)
#define NO_CHANNELS               (-1)
#define SENSE_FIELD_POS           (6)
#define SENSE_FIELD_MASK          (0xC0)

/**
 * @brief Macro for converting task-event index to an address of an event register.
 *
 * Macro utilizes the fact that registers are grouped together in ascending order.
 */
#define TE_IDX_TO_EVENT_ADDR(idx)    (nrf_gpiote_events_t)((uint32_t)NRF_GPIOTE_EVENTS_IN_0 + \
                                                           (sizeof(uint32_t) * (idx)))

/**
 * @brief Macro for converting task-event index of OUT task to an address of a task register.
 *
 * Macro utilizes the fact that registers are grouped together in ascending order.
 */
#define TE_OUT_IDX_TO_TASK_ADDR(idx) (nrf_gpiote_tasks_t)((uint32_t)NRF_GPIOTE_TASKS_OUT_0 + \
                                                          (sizeof(uint32_t) * (idx)))

#if defined(GPIOTE_FEATURE_SET_PRESENT) || defined(__SDK_DOXYGEN__)
/**
 * @brief Macro for converting task-event index of SET task to an address of a task register.
 *
 * Macro utilizes the fact that registers are grouped together in ascending order.
 */
#define TE_SET_IDX_TO_TASK_ADDR(idx) (nrf_gpiote_tasks_t)((uint32_t)NRF_GPIOTE_TASKS_SET_0 + \
                                                          (sizeof(uint32_t) * (idx)))

#endif // defined(GPIOTE_FEATURE_SET_PRESENT) || defined(__SDK_DOXYGEN__)

#if defined(GPIOTE_FEATURE_CLR_PRESENT) || defined(__SDK_DOXYGEN__)
/**
 * @brief Macro for converting task-event index of CLR task to an address of a task register.
 *
 * Macro utilizes the fact that registers are grouped together in ascending order.
 */
#define TE_CLR_IDX_TO_TASK_ADDR(idx) (nrf_gpiote_tasks_t)((uint32_t)NRF_GPIOTE_TASKS_CLR_0 + \
                                                          (sizeof(uint32_t) * (idx)))

#endif // defined(GPIOTE_FEATURE_CLR_PRESENT) || defined(__SDK_DOXYGEN__)

/*lint -save -e661*/
typedef struct
{
    nrf_drv_gpiote_evt_handler_t handlers[GPIOTE_CH_NUM + GPIOTE_CONFIG_NUM_OF_LOW_POWER_EVENTS];
    int8_t                       pin_assignments[NUMBER_OF_PINS];
    int8_t                       port_handlers_pins[GPIOTE_CONFIG_NUM_OF_LOW_POWER_EVENTS];
    nrf_drv_state_t              state;
} gpiote_control_block_t;

static gpiote_control_block_t m_cb;

__STATIC_INLINE bool pin_in_use(uint32_t pin)
{
    return (m_cb.pin_assignments[pin] != PIN_NOT_USED);
}


__STATIC_INLINE bool pin_in_use_as_non_task_out(uint32_t pin)
{
    return (m_cb.pin_assignments[pin] == PIN_USED);
}


__STATIC_INLINE bool pin_in_use_by_te(uint32_t pin)
{
    return (m_cb.pin_assignments[pin] >= 0 && m_cb.pin_assignments[pin] <
            GPIOTE_CH_NUM) ? true : false;
}


__STATIC_INLINE bool pin_in_use_by_port(uint32_t pin)
{
    return (m_cb.pin_assignments[pin] >= GPIOTE_CH_NUM);
}


__STATIC_INLINE bool pin_in_use_by_gpiote(uint32_t pin)
{
    return (m_cb.pin_assignments[pin] >= 0);
}


__STATIC_INLINE void pin_in_use_by_te_set(uint32_t                     pin,
                                          uint32_t                     channel_id,
                                          nrf_drv_gpiote_evt_handler_t handler,
                                          bool                         is_channel)
{
    m_cb.pin_assignments[pin] = channel_id;
    m_cb.handlers[channel_id] = handler;
    if (!is_channel)
    {
        m_cb.port_handlers_pins[channel_id - GPIOTE_CH_NUM] = (int8_t)pin;
    }
}


__STATIC_INLINE void pin_in_use_set(uint32_t pin)
{
    m_cb.pin_assignments[pin] = PIN_USED;
}


__STATIC_INLINE void pin_in_use_clear(uint32_t pin)
{
    m_cb.pin_assignments[pin] = PIN_NOT_USED;
}


__STATIC_INLINE int8_t channel_port_get(uint32_t pin)
{
    return m_cb.pin_assignments[pin];
}
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

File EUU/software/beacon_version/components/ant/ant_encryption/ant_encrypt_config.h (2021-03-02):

/* Copyright (c) 2015 Nordic Semiconductor. All Rights Reserved.
 *
 * The information contained herein is property of Nordic Semiconductor ASA.
 * Terms and conditions of usage are described in detail in NORDIC
 * SEMICONDUCTOR STANDARD SOFTWARE LICENSE AGREEMENT.
 *
 * Licensees are granted free, non-transferable use of the information. NO
 * WARRANTY of ANY KIND is provided. This heading must NOT be removed from
 * the file.
 *
 */

#ifndef ANT_ENCRYPT_CONFIG__
#define ANT_ENCRYPT_CONFIG__

/**@file
 *
 * @defgroup ant_encrypt_config ANT encryption configuration
 * @{
 * @ingroup  ant_sdk_utils
 *
 * @brief    Encryption configuration for the ANT stack and channels.
 *
 */

#include <stdint.h>

#include "sdk_errors.h"
#include "ant_stack_handler_types.h"

#ifdef __cplusplus
extern "C" {
#endif

/** @name Advanced burst configuration for encryption modules
 * @{
 */
#define ADV_BURST_CFG_MIN_SIZE          8 ///< Minimum size of the advance burst configuration data.
#define ADV_BURST_CFG_PACKET_SIZE_INDEX 1 ///< Index of the packet size field in the configuration data.
#define ADV_BURST_CFG_REQUIRED_FEATURES 2 ///< Index of the required features field in the configuration data.
#define ADV_BURST_CFG_OPTIONAL_FEATURES 5 ///< Index of the optional features field in the configuration data.
/**@} */

/** @brief ANT channel cryptographic configuration. */
typedef struct
{
    uint8_t mode;            ///< Encryption mode. See the encrypted channel defines in ant_parameters.h.
    uint8_t key_index;       ///< Index of encryption key.
    uint8_t decimation_rate; ///< Division of the master channel rate by the slave’s tracking channel rate.
} ant_encrypt_channel_settings_t;

/** @brief ANT encryption information. */
typedef union
{
    uint8_t * pp_array[3]; // For array access support.
    struct
    {
        uint8_t * p_encryption_id;   ///< Pointer to the encryption ID of the device (4 bytes).
        uint8_t * p_user_info;       ///< Pointer to the user information string (19 bytes).
        uint8_t * p_random_num_seed; ///< Pointer to the random number seed (16 bytes).
    } items;
} ant_encrypt_info_settings_t;

/** @brief Advanced burst settings used by the encrypted channel. */
typedef struct
{
    uint8_t packet_length;    ///< RF payload size. See the advanced burst configuration defines in ant_parameters.h.
    uint8_t required_feature; ///< Required advanced burst modes. See the advanced burst configuration defines in ant_parameters.h.
    uint8_t optional_feature; ///< Optional advanced burst modes. See the advanced burst configuration defines in ant_parameters.h.
} ant_encrypt_adv_burst_settings_t;

/**@brief ANT stack cryptographic configuration. */
typedef struct
{
    ant_encrypt_info_settings_t        info;               ///< Pointer to the encryption information structure.
    uint8_t                        * * pp_key;             ///< Pointer to an array for pointers to encryption keys. Each key must have a length of 16 bytes.
    uint8_t                            key_number;         ///< Number of encryption keys.
    ant_encrypt_adv_burst_settings_t * p_adv_burst_config; ///< Advanced burst configuration. If NULL, the advanced burst must be configured externally.
} ant_encrypt_stack_settings_t;

/**
 * @brief ANT encryption negotiation events.
 */
typedef enum
{
    ANT_ENC_EVT_NEGOTIATION_SUCCESS, ///< Negotiation success.
    ANT_ENC_EVT_NEGOTIATION_FAIL,    ///< Negotiation failure.
    ANT_ENC_EVT_CHANNEL_LOST         ///< Lost a channel. It's relevant only for slave channels.
} ant_encrypt_user_evt_t;

/**
 * @brief Event handler for ANT encryption user events.
 */
typedef void (* ant_encryp_user_handler_t)(uint8_t channel, ant_encrypt_user_evt_t event);

/**
 * @brief Macro for initializing an ANT encryption information structure.
 *
 * @param[in] P_ENC_ID         Pointer to the encryption ID of the device (4 bytes).
 * @param[in] P_USER_INFO      Pointer to the user information string (19 bytes).
 * @param[in] P_RAND_NUM_SEED  Pointer to the random number seed (16 bytes).
 */
#define ANT_CRYPTO_INFO_SETTINGS_INIT(P_ENC_ID, P_USER_INFO, P_RAND_NUM_SEED) \
    {                                                                         \
        .items =                                                              \
        {                                                                     \
            .p_encryption_id   = P_ENC_ID,                                    \
            .p_user_info       = P_USER_INFO,                                 \
            .p_random_num_seed = P_RAND_NUM_SEED                              \
        }                                                                     \
    }
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

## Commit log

2020-04-30 add PCB
    [S-SSHI.SchDoc, SCE.SchDoc, SCE5x5.PcbDoc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]
2020-04-30 fix some bugs
    [emu.PcbDoc, emu.SchDoc, nrf52832Base.PcbDoc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]
2020-05-19 update missing part of code
    [ant_encrypt_config.h]
2020-06-02 all can be compiled
    [emu.PcbDoc]
2020-09-13 change R1 R2 R3 in EMU ciruict
    [EMU.SchDoc]
2021-03-05 new version
    [EEU.PcbDoc, EEU.PrjPCB, EEU.SchDoc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]
